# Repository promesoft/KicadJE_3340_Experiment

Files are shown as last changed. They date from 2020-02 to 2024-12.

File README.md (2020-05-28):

# AS3340/CEM3340 Experiment
AS3340 Experiments

# Vital Components
Based on http://www.alfarzpp.lv/eng/sc/AS3340.pdf

Sourced through https://syntaxis.com.pl/en/voltage-controlled-oscilators/8-as3340-vco.html

# Status - Delivered
## Initial 
| Stage  | Detail | Status |
| --- | --- | --- |
| create material  | sch | done |
| | pcb | done  |
| | gerber | done |
| production  | | ok |
|  | produced | ok |
|  | delivered | ok |
## Preliminary validation
| Test  | Detail | Status |
| --- | --- | --- |
| Initial Inspection | Face | Looks good - nice alignment and finish |
| Initial Inspection | PCB | Several errors |
| Initial Technical Test |  | Several errors |
| Initial Product Test |  |  |

## Secondary validation
| Test  | Detail | Status |
| --- | --- |--- |
| Product Test |  | |
| Quality | | |
| Long Term Product Test |  |  |
| Power Draw |  | 

## Errata
### Errata - 3340
 - Sync circuit messed up in SCH
 - Fine pot reversed
 - D103 D104 should go to GND and + 5V

## Issues and Notes
### 3340 Faceplate and PCB does not match for input jacks
### + 6V -1V CV

# Pictures
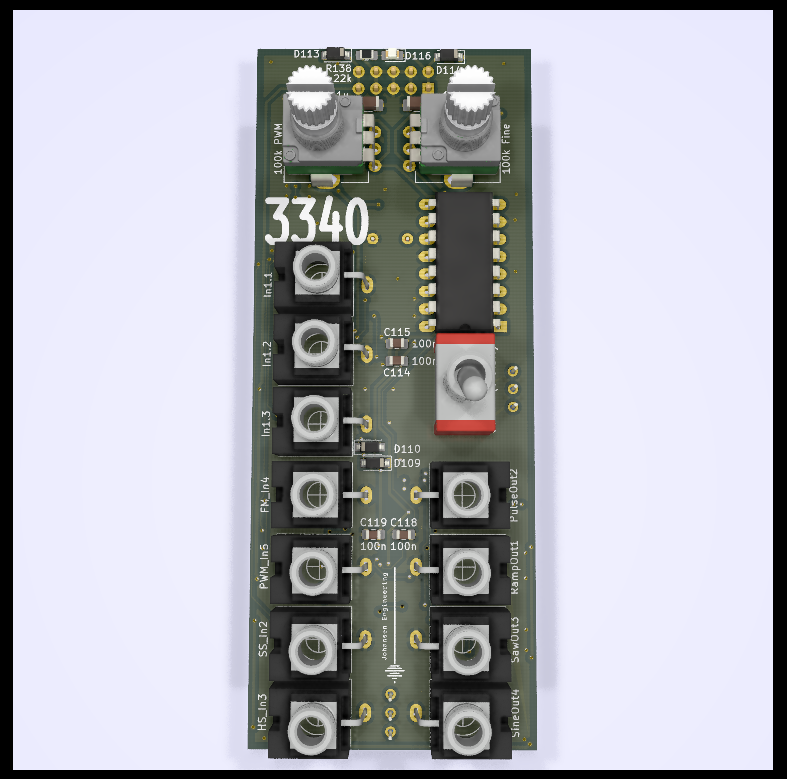
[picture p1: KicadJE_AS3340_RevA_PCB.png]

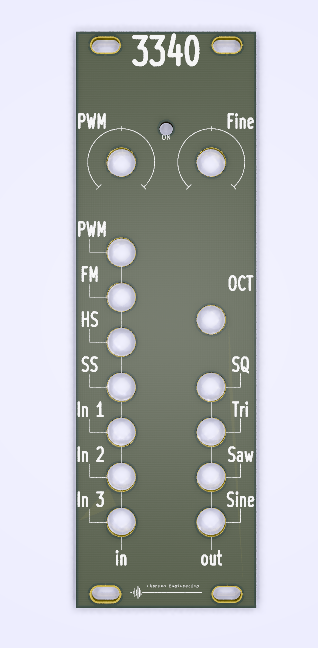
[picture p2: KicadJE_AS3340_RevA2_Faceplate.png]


# Schematic
## AS3340 Data Sheet
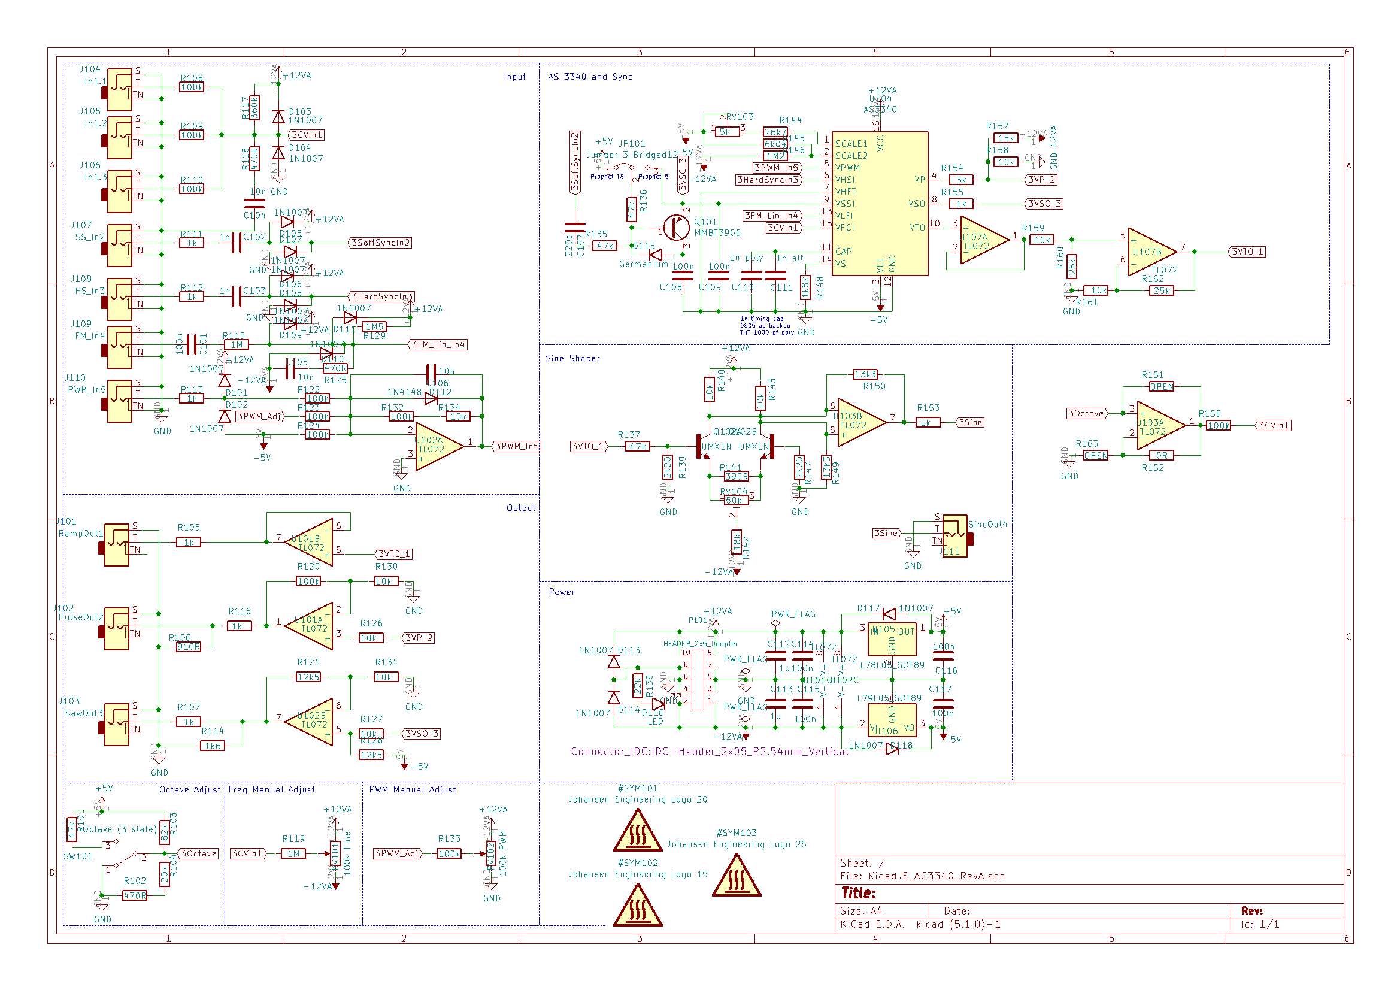
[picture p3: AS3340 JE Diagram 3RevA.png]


## Prototype

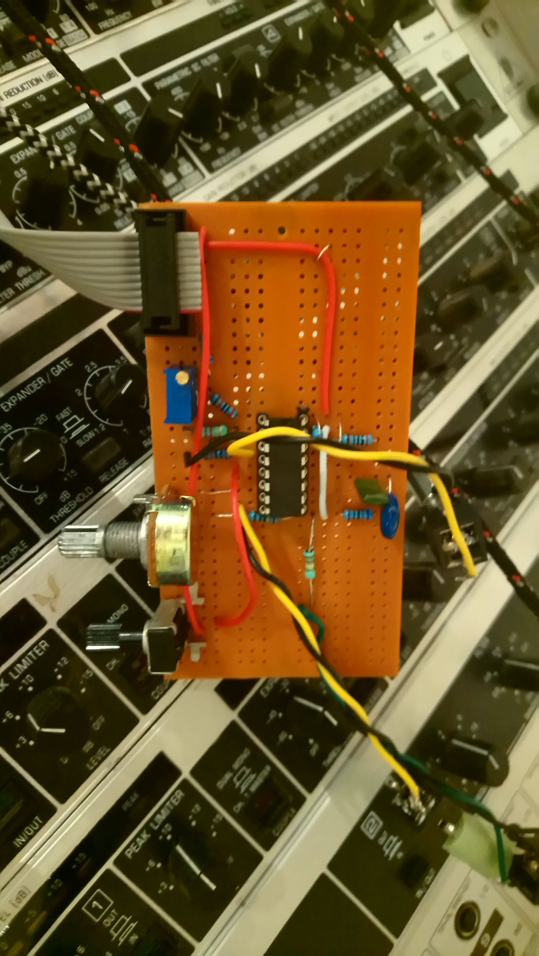
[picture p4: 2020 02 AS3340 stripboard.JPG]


Move from breadboard to stripboard as breadboard is not stable in any way.

Quick mods to get started
* 820R -> 680R (-12v)
* 470R -> 680R (CV in)
* 24k -> 20k (Rz tracking serial res)
* 1k8 -> 2k (Scale)
* 1M5 -> 1M (+12v pull up FM in)
* 5k6 -> 4k7 (scale adj RT)

Works ok for feature validation - but sync and PWM adjustment circuits should be included - as well as level adjustment.
Protection of the chip is also needed.
20K pot not needed.

# Inspiration
## AS3340 Data Sheet
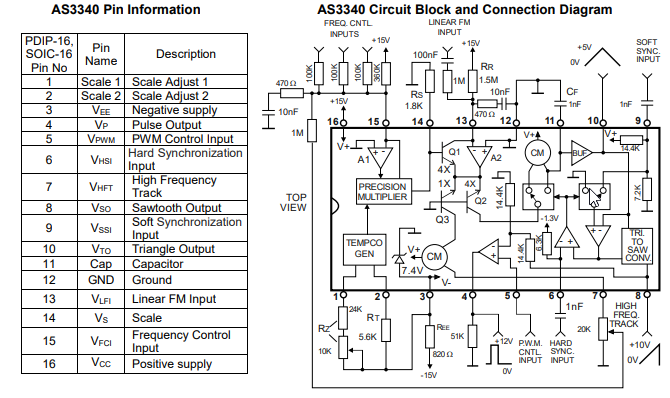
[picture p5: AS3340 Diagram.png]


http://www.alfarzpp.lv/eng/sc/AS3340.pdf

## CEM3340 Data Sheet - Via Electric Druid
CC BY-NC-SA 4.0
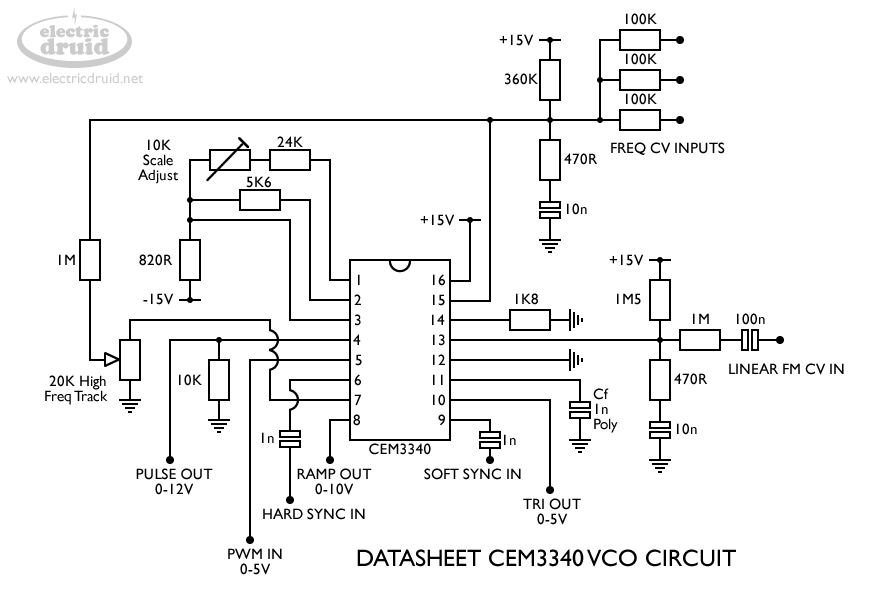
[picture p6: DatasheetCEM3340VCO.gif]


## CEM3340 Prophet 5 - Via Electric Druid
CC BY-NC-SA 4.0
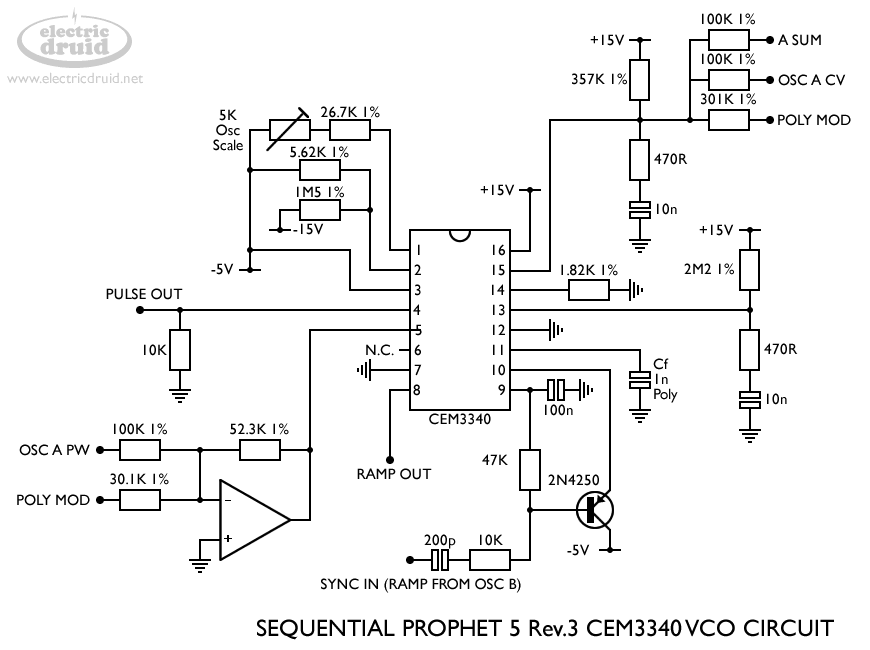
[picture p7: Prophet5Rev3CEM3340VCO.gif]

https://electricdruid.net/cem3340-vco-voltage-controlled-oscillator-designs/

## CEM3340 Prophet T8 - Via Electric Druid
CC BY-NC-SA 4.0

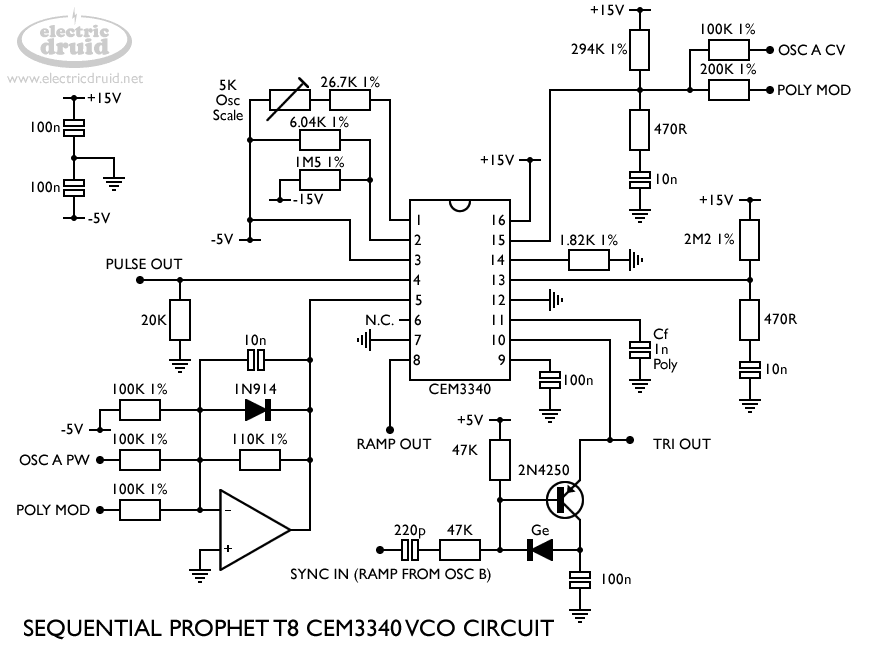
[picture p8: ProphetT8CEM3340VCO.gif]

https://electricdruid.net/cem3340-vco-voltage-controlled-oscillator-designs/

available under - https://creativecommons.org/licenses/by-nc-sa/4.0/

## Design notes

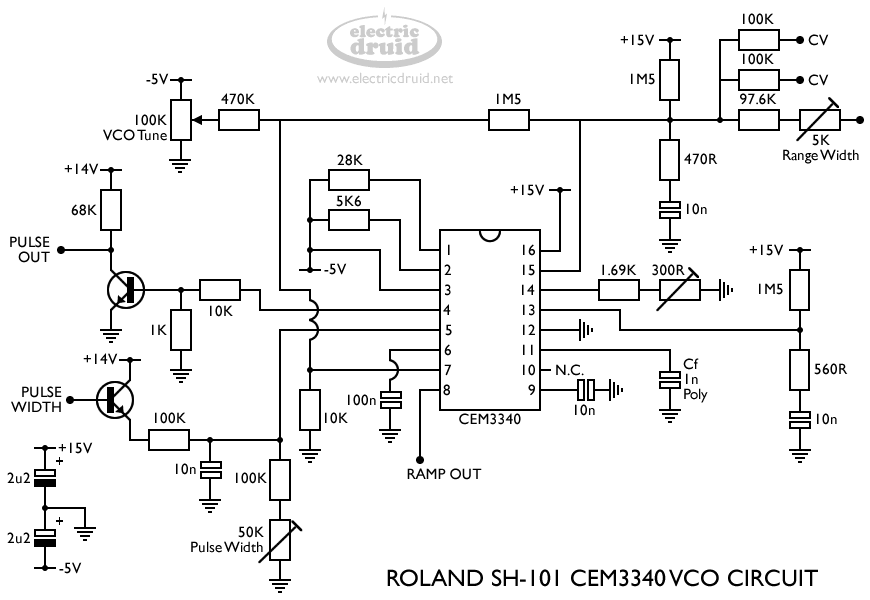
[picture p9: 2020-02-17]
SH101CEM3340VCO.gif

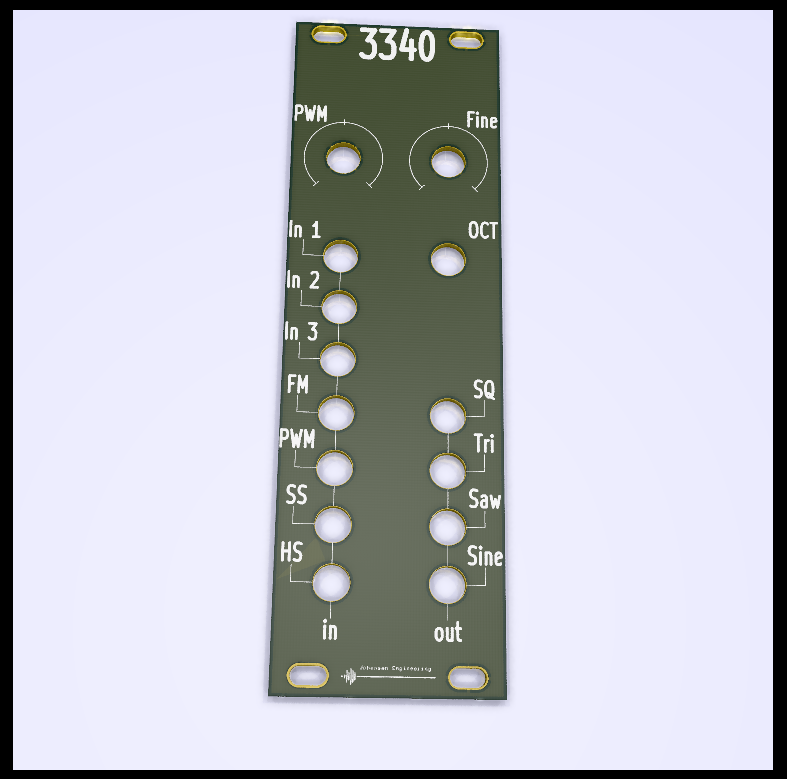
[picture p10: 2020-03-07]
KicadJE_AS3340_RevA_Faceplate.png

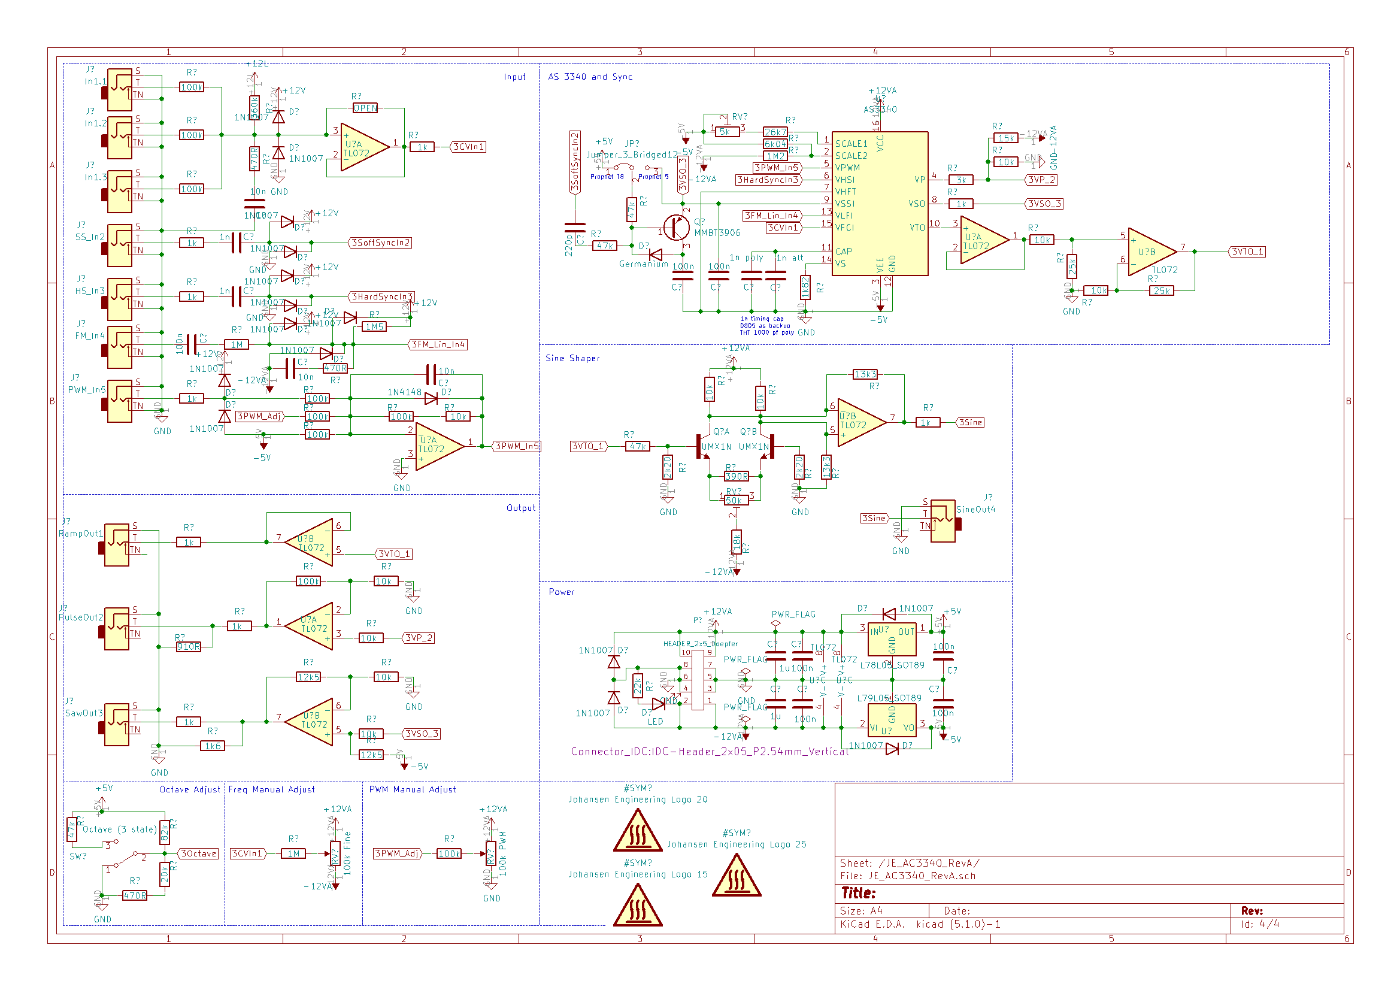
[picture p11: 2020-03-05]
AS3340 JE Diagram 3.png

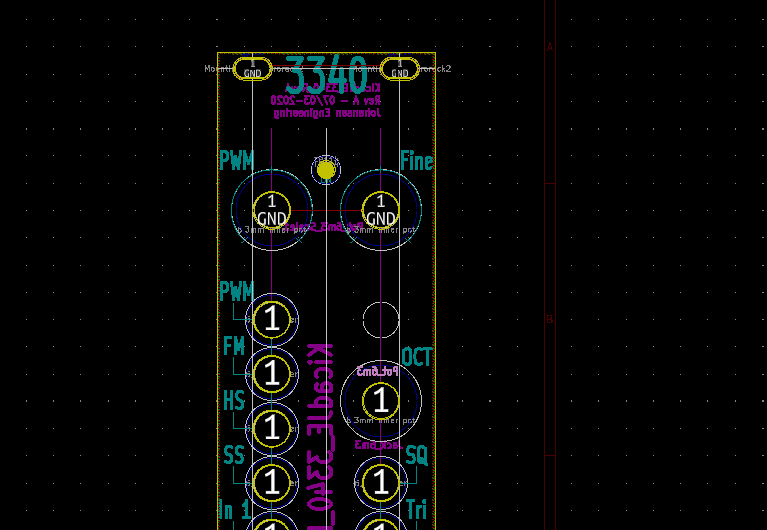
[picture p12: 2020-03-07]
KicadJE_AS3340_RevA2_Faceplate_Back.png

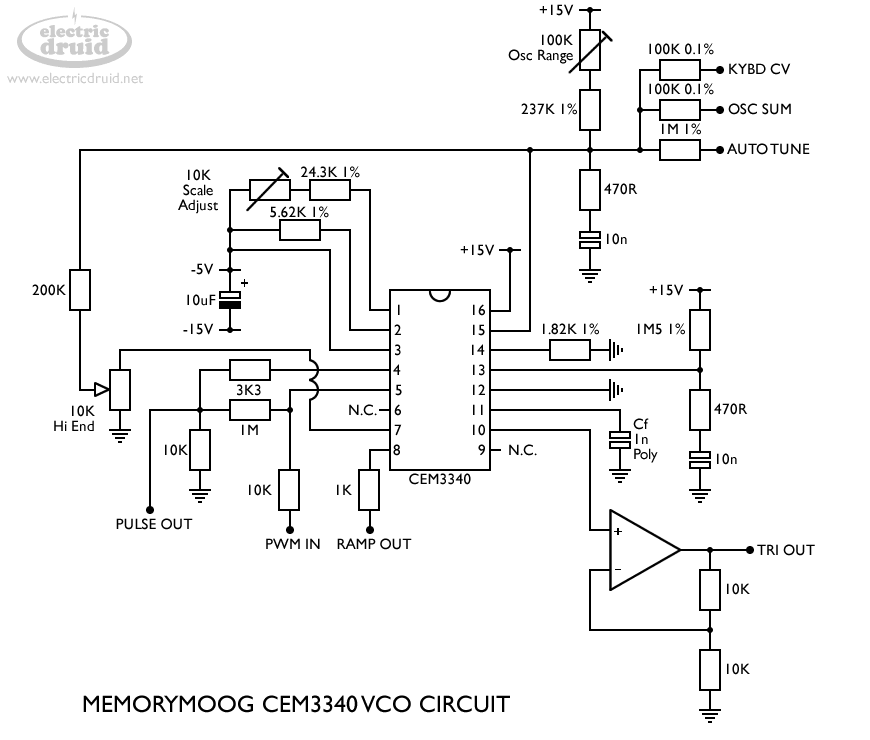
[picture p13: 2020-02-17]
MemoryMoogCEM3340VCO.gif

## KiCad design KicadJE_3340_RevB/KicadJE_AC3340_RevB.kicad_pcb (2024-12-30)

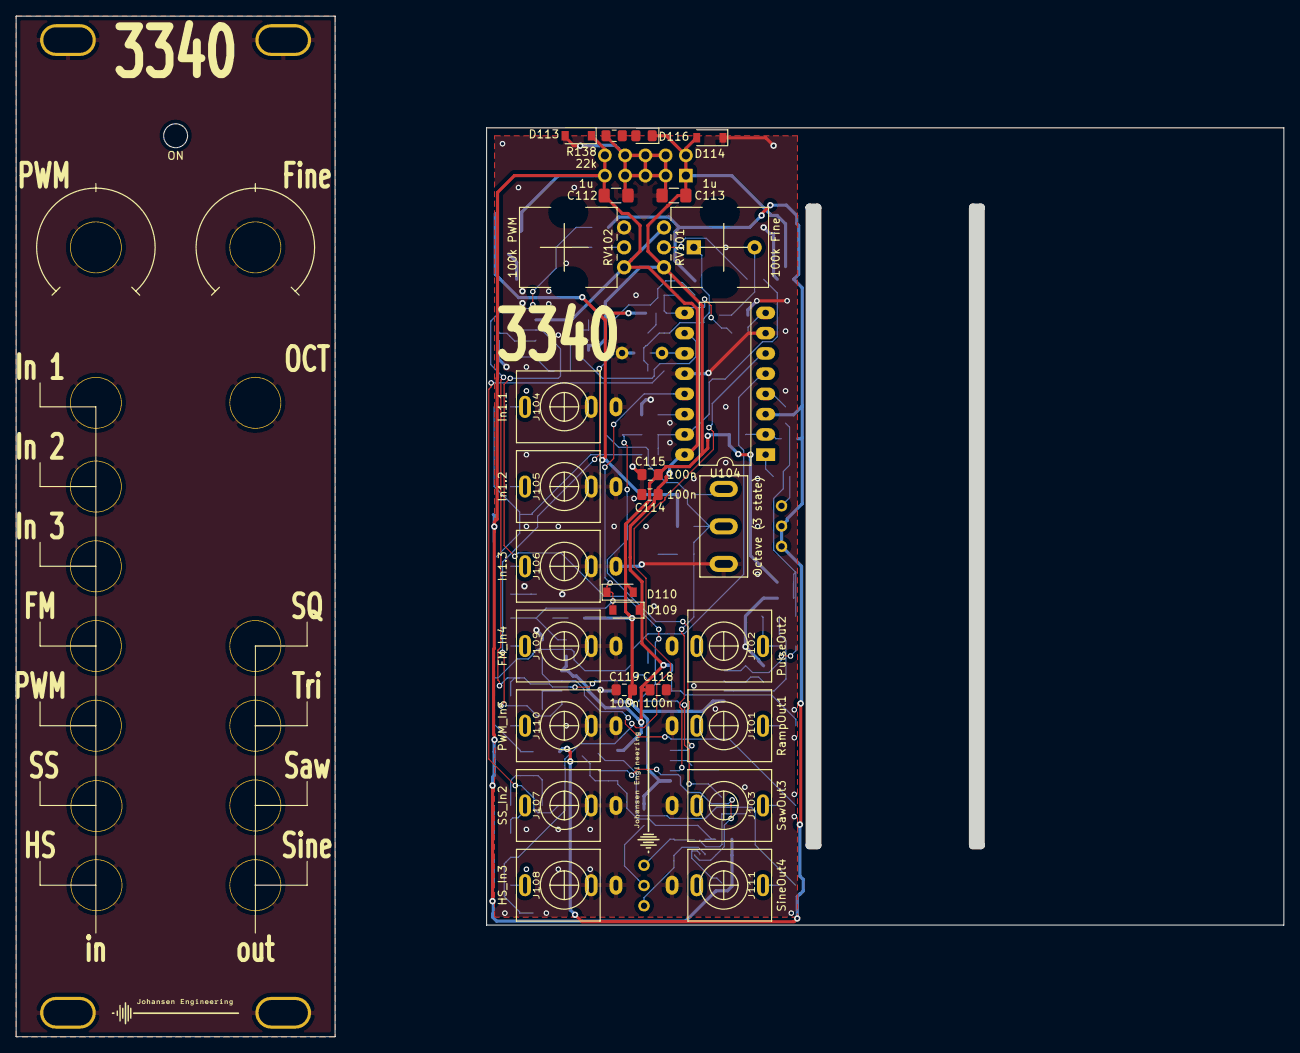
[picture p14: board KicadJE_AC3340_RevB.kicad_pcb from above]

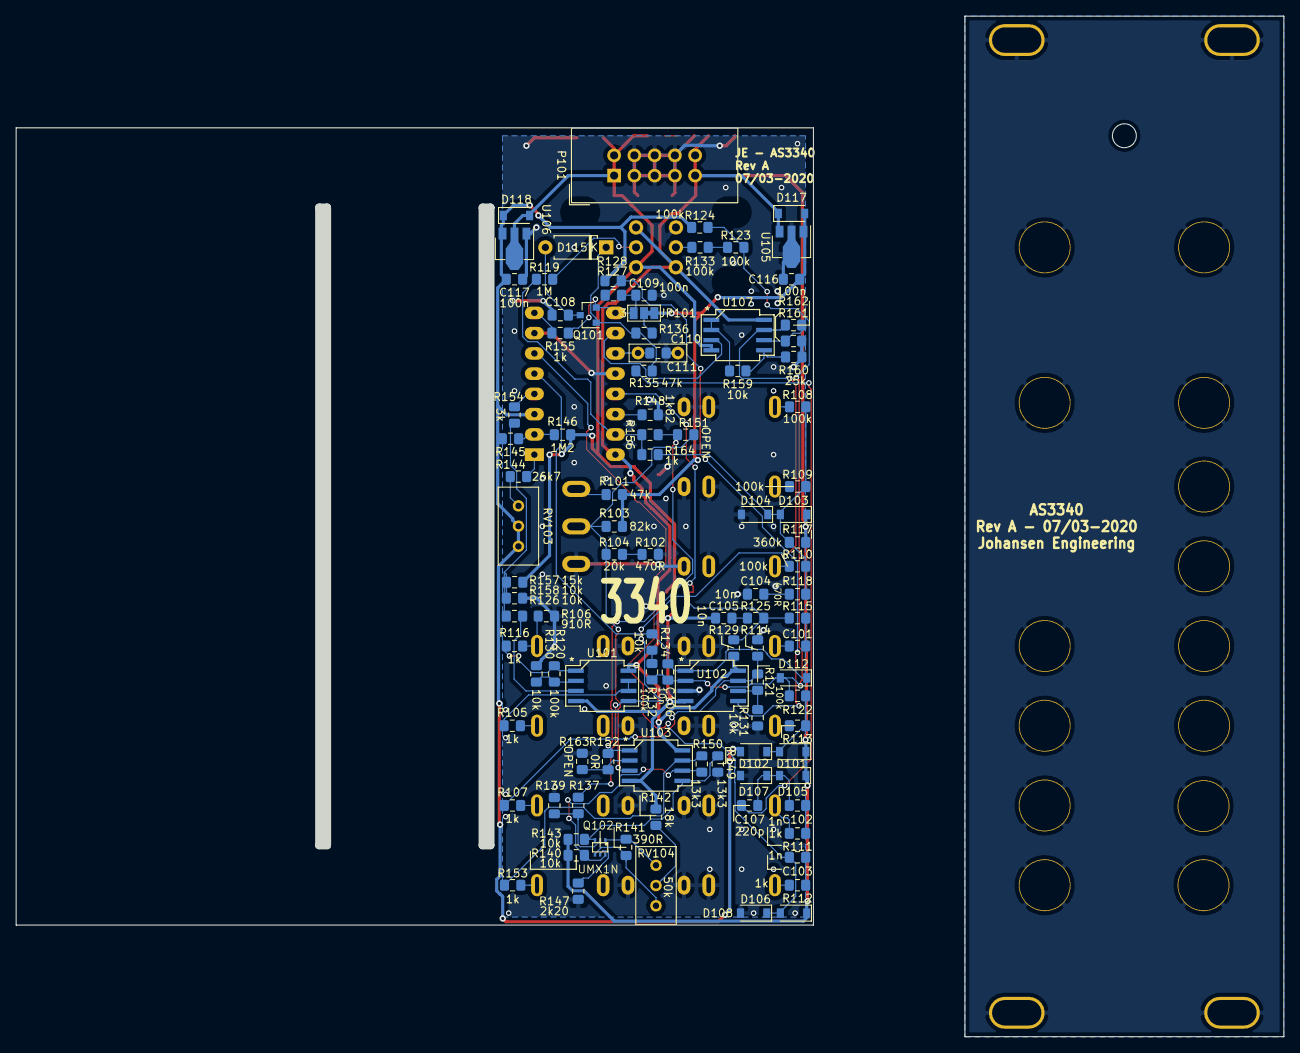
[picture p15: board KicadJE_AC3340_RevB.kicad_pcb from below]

Board: 2 copper layers, 100.0 x 100.0 mm, 146 parts (102 on the bottom side), 72 nets.

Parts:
C101, C108, C109, C114, C115, C116, C117, C118, C119: 100n; C_0805_2012Metric_Pad1.15x1.40mm_HandSolder
C102, C103: 1n; C_0805_2012Metric_Pad1.15x1.40mm_HandSolder
C104, C105, C106: 10n; C_0805_2012Metric_Pad1.15x1.40mm_HandSolder
C107: 220p; C_0805_2012Metric_Pad1.15x1.40mm_HandSolder
C110: 1n poly; C_Rect_L7.0mm_W2.0mm_P5.00mm
C111: 1n alt; C_0805_2012Metric_Pad1.15x1.40mm_HandSolder
C112, C113: 1u; C_1206_3216Metric_Pad1.42x1.75mm_HandSolder
D101, D102, D103, D104, D105, D106, D107, D108, D109, D110, D113, D114, D117, D118: 1N1007; D_SOD-123
D112: 1N4148; D_SOD-123
D115: Germanium; D_A-405_P7.62mm_Horizontal
D116: LED; LED_0805_2012Metric_Pad1.15x1.40mm_HandSolder
H101, H102, H103, H104: MountingHole_Pad; MountingHole_Eurorack3
H105: ON; LED_Hole_3mm
J101: RampOut1; PJ301SM
J102: PulseOut2; PJ301SM
J103: SawOut3; PJ301SM
J104: In1.1; PJ301SM
J105: In1.2; PJ301SM
J106: In1.3; PJ301SM
J107: SS_In2; PJ301SM
J108: HS_In3; PJ301SM
J109: FM_In4; PJ301SM
J110: PWM_In5; PJ301SM
J111: SineOut4; PJ301SM
JP101: Jumper; SolderJumper-3_P1.3mm_Bridged12_Pad1.0x1.5mm_NumberLabels
P101: HEADER_2x5_Doepfer; IDC-Header_2x05_P2.54mm_Vertical
Q101: MMBT3906; SOT-23
Q102: UMX1N; UMX1N_UMT6_DualNPN
R101, R135, R136, R137: 47k; R_0805_2012Metric_Pad1.15x1.40mm_HandSolder
R102, R118, R125: 470R; R_0805_2012Metric_Pad1.15x1.40mm_HandSolder
R103: 82k; R_0805_2012Metric_Pad1.15x1.40mm_HandSolder
R104: 20k; R_0805_2012Metric_Pad1.15x1.40mm_HandSolder
R105, R107, R111, R112, R113, R116, R153, R155, R164: 1k; R_0805_2012Metric_Pad1.15x1.40mm_HandSolder
R106: 910R; R_0805_2012Metric_Pad1.15x1.40mm_HandSolder
R108, R109, R110, R120, R122, R123, R124, R132, R133, R156: 100k; R_0805_2012Metric_Pad1.15x1.40mm_HandSolder
R114: 1k6; R_0805_2012Metric_Pad1.15x1.40mm_HandSolder
R115, R119: 1M; R_0805_2012Metric_Pad1.15x1.40mm_HandSolder
R117: 360k; R_0805_2012Metric_Pad1.15x1.40mm_HandSolder
R121, R128: 12k5; R_0805_2012Metric_Pad1.15x1.40mm_HandSolder
R126, R127, R130, R131, R134, R140, R143, R158, R159, R161: 10k; R_0805_2012Metric_Pad1.15x1.40mm_HandSolder
R129: 1M5; R_0805_2012Metric_Pad1.15x1.40mm_HandSolder
R138: 22k; R_0805_2012Metric_Pad1.15x1.40mm_HandSolder
R139, R147: 2k20; R_0805_2012Metric_Pad1.15x1.40mm_HandSolder
R141: 390R; R_0805_2012Metric_Pad1.15x1.40mm_HandSolder
R142: 18k; R_0805_2012Metric_Pad1.15x1.40mm_HandSolder
R144: 26k7; R_0805_2012Metric_Pad1.15x1.40mm_HandSolder
R145: 6k04; R_0805_2012Metric_Pad1.15x1.40mm_HandSolder
R146: 1M2; R_0805_2012Metric_Pad1.15x1.40mm_HandSolder
R148: 1k82; R_0805_2012Metric_Pad1.15x1.40mm_HandSolder
R149, R150: 13k3; R_0805_2012Metric_Pad1.15x1.40mm_HandSolder
R151, R163: OPEN; R_0805_2012Metric_Pad1.15x1.40mm_HandSolder
R152: 0R; R_0805_2012Metric_Pad1.15x1.40mm_HandSolder
R154: 3k; R_0805_2012Metric_Pad1.15x1.40mm_HandSolder
R157: 15k; R_0805_2012Metric_Pad1.15x1.40mm_HandSolder
R160, R162: 25k; R_0805_2012Metric_Pad1.15x1.40mm_HandSolder
RV101: 100k Fine; Potentiometer_China_RK09_Single_Vertical_AJ
RV102: 100k PWM; Potentiometer_China_RK09_Single_Vertical_AJ
RV103: 5k; Potentiometer_Bourns_3296W_Vertical
RV104: 50k; Potentiometer_Bourns_3296W_Vertical
SW101: Octave (3 state); SP1MS1
TP101: Oct; Pot_6m3
TP102: In1; Jack_6m3
TP103: In2; Jack_6m3
TP104: In3; Jack_6m3
TP105: SS; Jack_6m3
TP106: HS; Jack_6m3
TP107: FM; Jack_6m3
TP108: PWM; Jack_6m3
TP109: Tri; Jack_6m3
TP110: SQ; Jack_6m3
TP111: Saw; Jack_6m3
TP112: Fine; Pot_6m3_scale1
TP113: PWM; Pot_6m3_scale1
TP115: 3m5 jack; Jack_6m3
U101, U102, U103, U107: TL072; AJ_SO-8_5.3x6.2mm_P1.27mm
U104: AS3340; DIP-16_W10.16mm_LongPads
U105: L78L05_SOT89; SOT-89-3
U106: L79L05_SOT89; SOT-89-3

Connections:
3CVIn1: R119.2, R156.1, R164.1, U104.15
3FM_Lin_In4: D109.2, D110.1, R115.1, R125.2, R129.2, U104.13
3HardSyncIn3: C103.1, D106.2, D108.1, U104.6
3Octave: R103.1, R104.2, R151.2, SW101.2, U103.3
3PWM_Adj: R123.2, R133.2
3PWM_In5: C106.2, D112.1, R134.1, U102.1, U104.5
3Sine: J111.T, R153.1
3SoftSyncIn2: C102.1, C107.2, D105.2, D107.1
3VP_2: R126.1, R154.1, R157.2, R158.2
3VSO_3: C109.2, JP101.3, Q101.2, R127.1, R155.1, U104.9
3VTO_1: R137.2, R162.1, U101.5, U107.7
+5V: C116.2, D117.2, JP101.1, R101.2, R103.2, U105.1
+12VA: C112.1, C114.1, C118.1, D101.1, D103.1, D105.1, D106.1, D109.1, D113.1, D117.1, P101.9, P101.10, R117.2, R129.1, R140.2, R143.2, RV101.3, RV102.3, U101.8, U102.8, U103.8, U104.16, U105.3, U107.8
-5V: C117.2, D102.2, D118.1, R124.2, R128.1, R145.2, RV103.1, RV103.2, U104.3, U106.3
-12VA: C105.1, C113.2, C115.2, C119.2, D110.2, D114.2, D116.1, D118.2, P101.1, P101.2, R142.2, R146.2, R157.1, RV101.1, U101.4, U102.4, U103.4, U106.2, U107.4
GND: C104.1, C108.1, C109.1, C110.1, C111.2, C112.2, C113.1, C114.2, C115.1, C116.1, C117.1, C118.2, C119.1, D104.2, D107.2, D108.2, D113.2, D114.1, H101.1, H102.1, H103.1, H104.1, J101.S, J102.S, J103.S, J104.S, J104.TN, J105.S, J105.TN, J106.S, J106.TN, J107.S, J107.TN, J108.S, J108.TN, J109.S, J109.TN, J110.S, J110.TN, J111.S, P101.3, P101.4, P101.5, P101.6, P101.7, P101.8, R102.2, R106.1, R114.2, R130.1, R131.1, R138.2, R139.1, R147.1, R148.1, R149.2, R158.1, R160.1, R161.2, R163.2, RV102.1, SW101.1, TP101.1, TP102.1, TP103.1, TP104.1, TP105.1, TP106.1, TP107.1, TP108.1, TP109.1, TP110.1, TP111.1, TP112.1, TP113.1, TP115.1, U102.3, U104.7, U104.12, U105.2, U106.1
unnamed: C101.1, R115.2
unnamed: C101.2, J109.T
unnamed: C102.2, R111.1
unnamed: C103.2, R112.1
unnamed: C104.2, R118.1
unnamed: C105.2, R125.1
unnamed: C106.1, D112.2, R122.1, R123.1, R124.1, R132.2, U102.2
unnamed: C107.1, R135.2
unnamed: C108.2, D115.2, Q101.3
unnamed: C110.2, C111.1, U104.11
unnamed: D101.2, D102.1, R113.1, R122.2
unnamed: D103.2, D104.1, R108.1, R109.1, R110.1, R117.1, R118.2, R164.2
unnamed: D115.1, Q101.1, R135.1, R136.1
unnamed: D116.2, R138.1
unnamed: J101.T, R105.2
unnamed: J102.T, R106.2, R116.2
unnamed: J103.T, R107.2
unnamed: J104.T, R108.2
unnamed: J105.T, R109.2
unnamed: J106.T, R110.2
unnamed: J107.T, R111.2
unnamed: J108.T, R112.2
unnamed: J110.T, R113.2
unnamed: JP101.2, R136.2
unnamed: Q102.1, R141.2, RV104.1
unnamed: Q102.2, R137.1, R139.2
unnamed: Q102.3, R143.1, R149.1, U103.5
unnamed: Q102.4, R141.1, RV104.3
unnamed: Q102.5, R147.2
unnamed: Q102.6, R140.1, R150.1, U103.6
unnamed: R101.1, SW101.3
unnamed: R102.1, R104.1
unnamed: R105.1, U101.6, U101.7
unnamed: R107.1, R114.1, R121.2, U102.7
unnamed: R116.1, R120.2, U101.1
unnamed: R119.1, RV101.2
unnamed: R120.1, R130.2, U101.2
unnamed: R121.1, R131.2, U102.6
unnamed: R126.2, U101.3
unnamed: R127.2, R128.2, U102.5
unnamed: R132.1, R134.2
unnamed: R133.1, RV102.2
unnamed: R142.1, RV104.2
unnamed: R144.1, U104.1
unnamed: R144.2, RV103.3
unnamed: R145.1, R146.1, U104.2
unnamed: R148.2, U104.14
unnamed: R150.2, R153.2, U103.7
unnamed: R151.1, R152.1, R156.2, U103.1
unnamed: R152.2, R163.1, U103.2
unnamed: R154.2, U104.4
unnamed: R155.2, U104.8
unnamed: R159.1, R160.2, U107.5
unnamed: R159.2, U107.1, U107.2
unnamed: R161.1, R162.2, U107.6
unnamed: U104.10, U107.3

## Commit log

2020-02-17 Initial sch
    [KicadJE_3340_Experiment.kicad_pcb, KicadJE_3340_Experiment.sch, KicadJE_AS3340_datasheet.sch]
2020-02-17 two sub sheets made ready
    incomplete
    [KicadJE_3340_Experiment.sch, KicadJE_AS3340_datasheet.sch, KicadJE_AS3340_prophet8.sch]
2020-02-17 Datasheet initial done sch
    [KicadJE_AS3340_datasheet.sch]
2020-02-17 protection initiated
    prophet circuit initiated
    [KicadJE_3340_Experiment.sch, KicadJE_AS3340_datasheet.sch, KicadJE_AS3340_prophet8.sch]
2020-02-19 Datasheet input protection
    [KicadJE_AS3340_datasheet.sch, KicadJE_AS3340_prophet8.sch]
2020-02-29 T8 coming alive
    [KicadJE_AS3340_prophet8.sch, _saved_KicadJE_AS3340_prophet8.sch]
2020-02-29 AS 3340 JE initiated
    [JE_AC3340_RevA.sch, KicadJE_3340_Experiment.sch, KicadJE_AS3340_datasheet.sch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]
2020-03-01 Octave switch JE
    [JE_AC3340_RevA.sch]
2020-03-01 cleaning up and migrating data sheet features
    [JE_AC3340_RevA.sch]
2020-03-01 Label JE 3 + Pot's
    [JE_AC3340_RevA.sch]
2020-03-05 Initial Diagram 3
    [JE_AC3340_RevA.sch]
2020-03-05 base PCB
    [KicadJE_AC3340_RevA.kicad_pcb, KicadJE_AC3340_RevA.sch]
2020-03-05 DRC Done
    [KicadJE_AC3340_RevA.sch]
2020-03-06 rev a
    [KicadJE_AC3340_RevA.kicad_pcb, _saved_KicadJE_AC3340_RevA.sch]
2020-03-07 Update KicadJE_AC3340_RevA.kicad_pcb
    Front Panel Guides
    [KicadJE_AC3340_RevA.kicad_pcb]
2020-03-07 Minor rearrangement
    remove 2 labels
    [KicadJE_AC3340_RevA.sch, _saved_KicadJE_AC3340_RevA.sch]
2020-03-07 Update KicadJE_AC3340_RevA.kicad_pcb
    Faceplate labels
    [KicadJE_AC3340_RevA.kicad_pcb]
2020-03-07 Faceplate Gerber - Zip
    [KicadJE_AC3340_RevA_Faceplate-B_Cu.gbr, KicadJE_AC3340_RevA_Faceplate-B_Mask.gbr, KicadJE_AC3340_RevA_Faceplate-B_Paste.gbr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]
2020-03-07 Mounting holes in schematic
    Prepare for next faceplate
    [KicadJE_AC3340_RevA.sch]
2020-03-07 Create _saved_KicadJE_AC3340_RevA.sch
    With faceplate assignments
    [_saved_KicadJE_AC3340_RevA.sch]
2020-03-07 LED hole
    [KicadJE_AC3340_RevA.sch, _saved_KicadJE_AC3340_RevA.sch]
2020-03-07 TP -> mounting holes + ERC
    [KicadJE_AC3340_RevA.kicad_pcb, KicadJE_AC3340_RevA.sch]
2020-03-07 Faceplate A2
    change order of inputs
    move octave
    move led hole
    [KicadJE_AC3340_RevA.kicad_pcb, KicadJE_AC3340_RevA1_Faceplate.kicad_pcb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]
2020-03-07 LED PWR moved
    [KicadJE_AC3340_RevA.kicad_pcb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]
2020-03-07 main components placed
    [KicadJE_AC3340_RevA.kicad_pcb]
2020-03-07 fix in sine section
    [KicadJE_AC3340_RevA.kicad_pcb, KicadJE_AC3340_RevA.sch]
2020-03-08 Protection Diodes
    [KicadJE_AC3340_RevA.kicad_pcb, KicadJE_AC3340_RevA.sch]
2020-03-08 Update KicadJE_AC3340_RevA.kicad_pcb
    All Capacitors placed
    [KicadJE_AC3340_RevA.kicad_pcb]
2020-03-08 Update KicadJE_AC3340_RevA.kicad_pcb
    Initial routing
    [KicadJE_AC3340_RevA.kicad_pcb]
2020-03-08 Update KicadJE_AC3340_RevA.kicad_pcb
    DRC
    [KicadJE_AC3340_RevA.kicad_pcb]
2020-03-08 JLC order number
    [KicadJE_AC3340_RevA_Faceplate-B_Cu.gbr, KicadJE_AC3340_RevA_Faceplate-B_Mask.gbr, KicadJE_AC3340_RevA_Faceplate-B_Paste.gbr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]
2020-04-07 RevB init
    [KicadJE_AC3340_RevB.kicad_pcb, KicadJE_AC3340_RevB.sch]
2020-04-08 Update KicadJE_AC3340_RevB.sch
    Fix misc errata from RevA - not complete
    [KicadJE_AC3340_RevB.sch]
2021-05-06 Saved in newer kicad
    [KicadJE_AC3340_RevA.sch]
2024-12-30 long time ago
    [KicadJE_AC3340_RevB.kicad_pcb, KicadJE_AC3340_RevB.kicad_sch]
